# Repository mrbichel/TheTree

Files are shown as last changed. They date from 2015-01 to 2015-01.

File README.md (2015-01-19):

Helpful notes

tube 
ø indre 105
ø ydre 110

Power input 12 V

Calculations:
- LED current is approximately equal to: 0.5 / R3
- R3 power: the power dissipated by the resistor is approximately: 0.25 / R3. choose a resistor value at least 2x the power calculated so the resistor does not get burning hot.

so for 700mA LED current:
R3 = 0.5 / 0.7 = 0.71 ohms. closest standard resistor is 0.75 ohms.
R3 power = 0.25 / 0.71 = 0.35 watts. we'll need at least a 1/2 watt rated resistor.

Brand new and high quality.
High brightness, light and color consistency.
Color: Red, Green, Blue.
Viewing Angle: 140 degree.
Wavelength: R:620-630nm G:515-525nm B:460-470nm.
Voltage(Vf): R:2.0-2.5V G:3.2-3.6V B:3.2-3.86.
Luminous intensity: R:30-35lm G:40-45lm B:15-20lm.
Current: each 350mA

Wo for 350mA LED current:
R3 = 0.5 / 0.35 = 1.42857142857 ohms. closest standard resistor is 1.5 ohms.
R3 power = 0.25 / 1.42857142857 = 0.175 watts.
We use two 3.3 Ohm resistors

3 in parralell calculation
We have 350 mA LEDS
x3 = 1050

R3 = 0.5/1.05 = 0.47619047619
R3 power = 0.25 / 0.47619047619 = 0.525 W 

Standard resistors are 1/4W so 2 of them si okish 
In parralllel the closest we get to 0.47619047619 ohm with two standard resistors is with two 1 ohm resistors

    pcb2gcode --back /home/parallels/Desktop/psf/TheTree/3leds/series/inseries_copperBottom.gbl --drill   /home/parallels/Desktop/psf/TheTree/3leds/series/inseries_drill.txt --outline /home/parallels/Desktop/psf/TheTree/3leds/series/inseries_contour.gm1 --zwork -0.2 --zsafe 25.0 --mill-feed 6 --mill-speed 30000 --metric --offset 2.0 --basename johandrill --zdrill -2.0 --zchange 10.0 --drill-feed 6 --drill-speed 20000 --cutter-diameter 3.0 --zcut -2.0 -cut-speed 20000
---

    pcb2gcode --back /home/parallels/Desktop/psf/TheTree/3leds/series/inseries_copperBottom.gbl --drill /home/parallels/Desktop/psf/TheTree/3leds/series/inseries_drill.txt --outline /home/parallels/Desktop/psf/TheTree/3leds/series/inseries_contour.gm1 --zwork -0.2 --zsafe 25.0 --mill-feed 6 --mill-speed 30000 --metric --offset 50 --basename johandrill --zdrill -2.0 --zchange 10.0 --drill-feed 6 --drill-speed 20000 --cutter-diameter 3.0 --zcut -2.0 --cut-speed 20000 --milldrill --fill-outline --outline-width 2

    --fill-outline --outline-width 2 for using fritzing outline file

http://chilipeppr.com/tinyg

http://simplegcoder.com/js_editor/

http://jscut.org/jscut.html#

http://simplegcoder.com/js_editor_framework/

http://fablabamersfoort.nl/drill2gcode/

    pcb2gcode --back /home/parallels/Desktop/psf/TheTree/3leds/series/inseries_copperBottom.gbl --drill /home/parallels/Desktop/psf/TheTree/3leds/series/inseries_drill.txt --outline /home/parallels/Desktop/psf/TheTree/3leds/series/inseries_contour.gm1 --zwork -0.008 --zsafe 1 --mill-feed 6 --mill-speed 30000 --offset 1 --basename __newdrill --zdrill -0.07 --zchange 0.4 --drill-feed 6 --drill-speed 20000 --cutter-diameter 0.015 --zcut -0.07 --cut-speed 20000 --fill-outline --outline-width 0.01

Remember to connect MAX485 pin to ground with jumper

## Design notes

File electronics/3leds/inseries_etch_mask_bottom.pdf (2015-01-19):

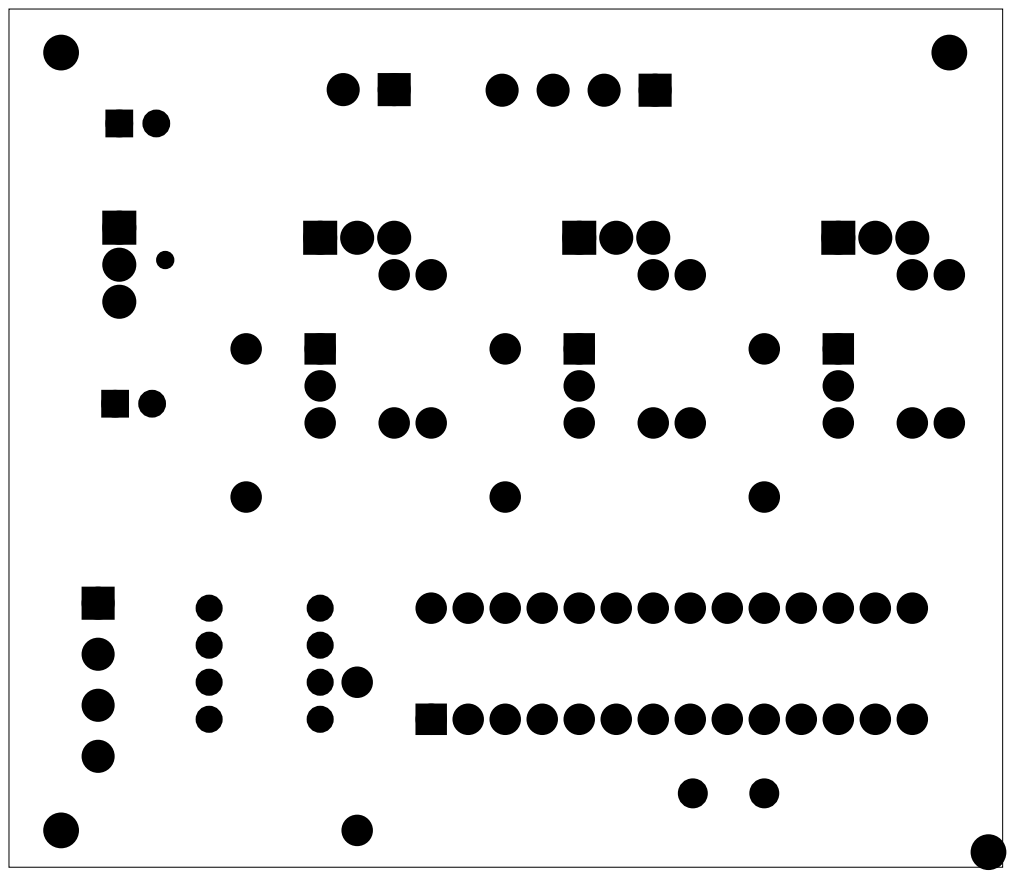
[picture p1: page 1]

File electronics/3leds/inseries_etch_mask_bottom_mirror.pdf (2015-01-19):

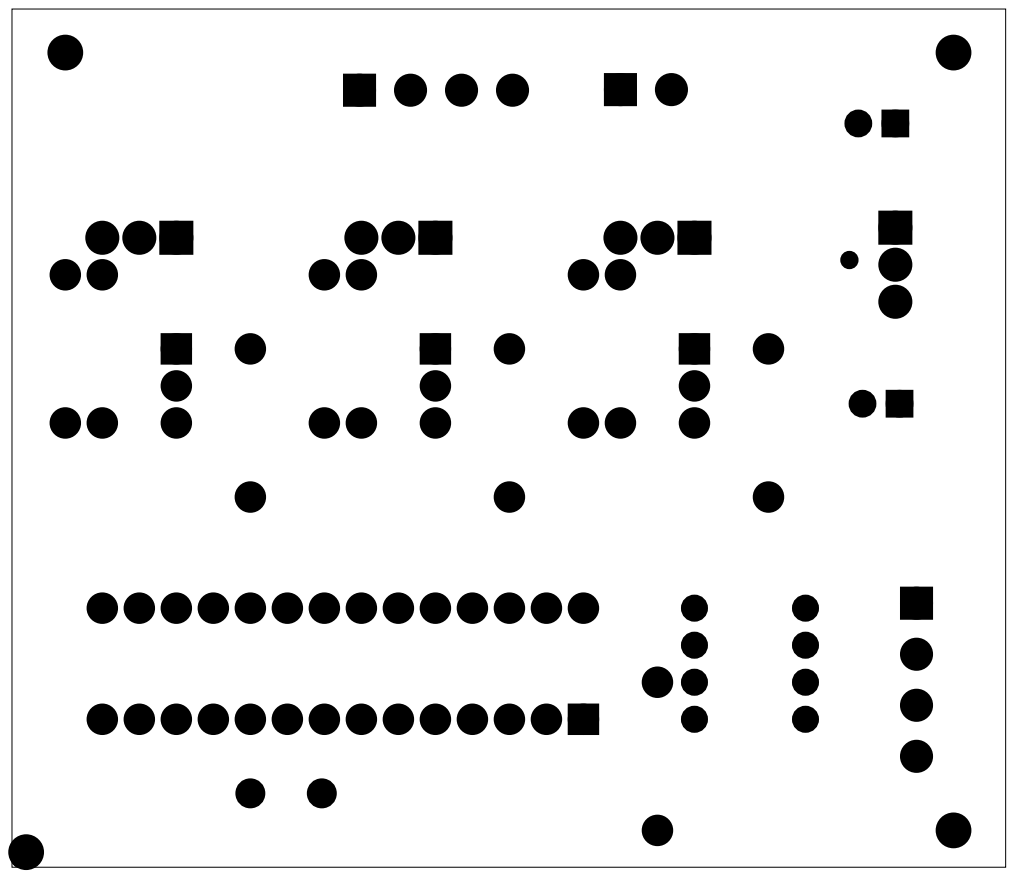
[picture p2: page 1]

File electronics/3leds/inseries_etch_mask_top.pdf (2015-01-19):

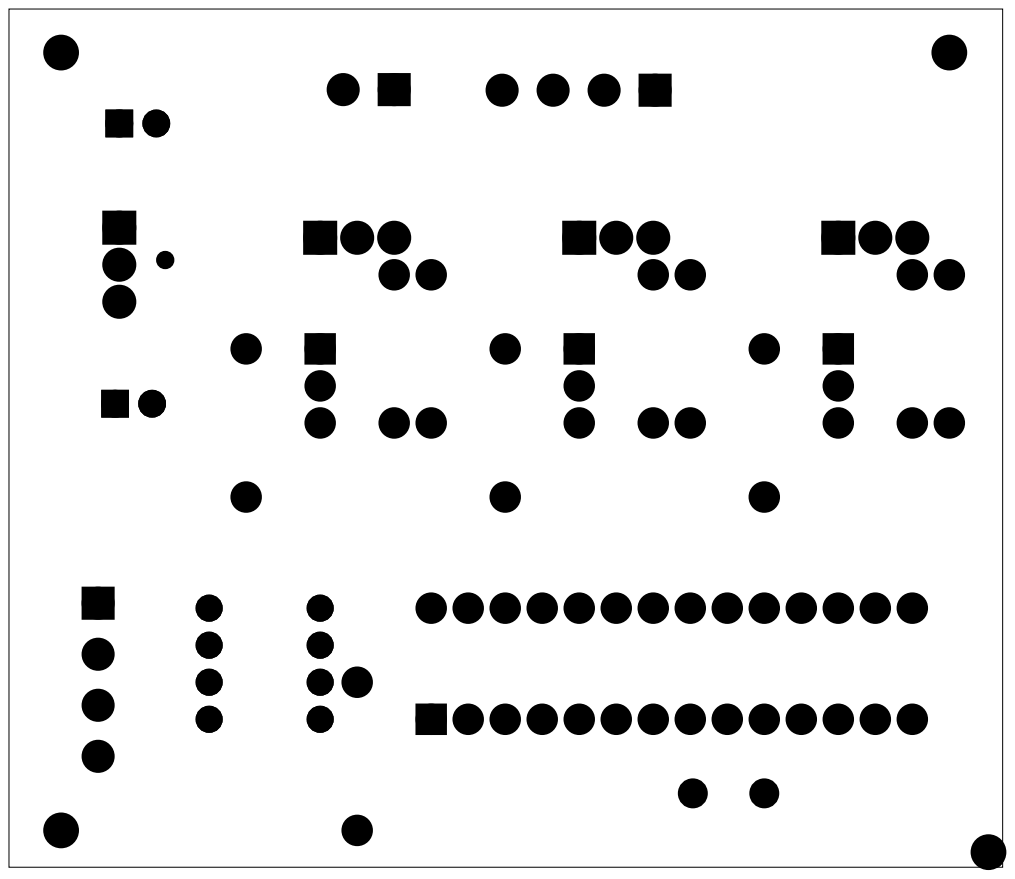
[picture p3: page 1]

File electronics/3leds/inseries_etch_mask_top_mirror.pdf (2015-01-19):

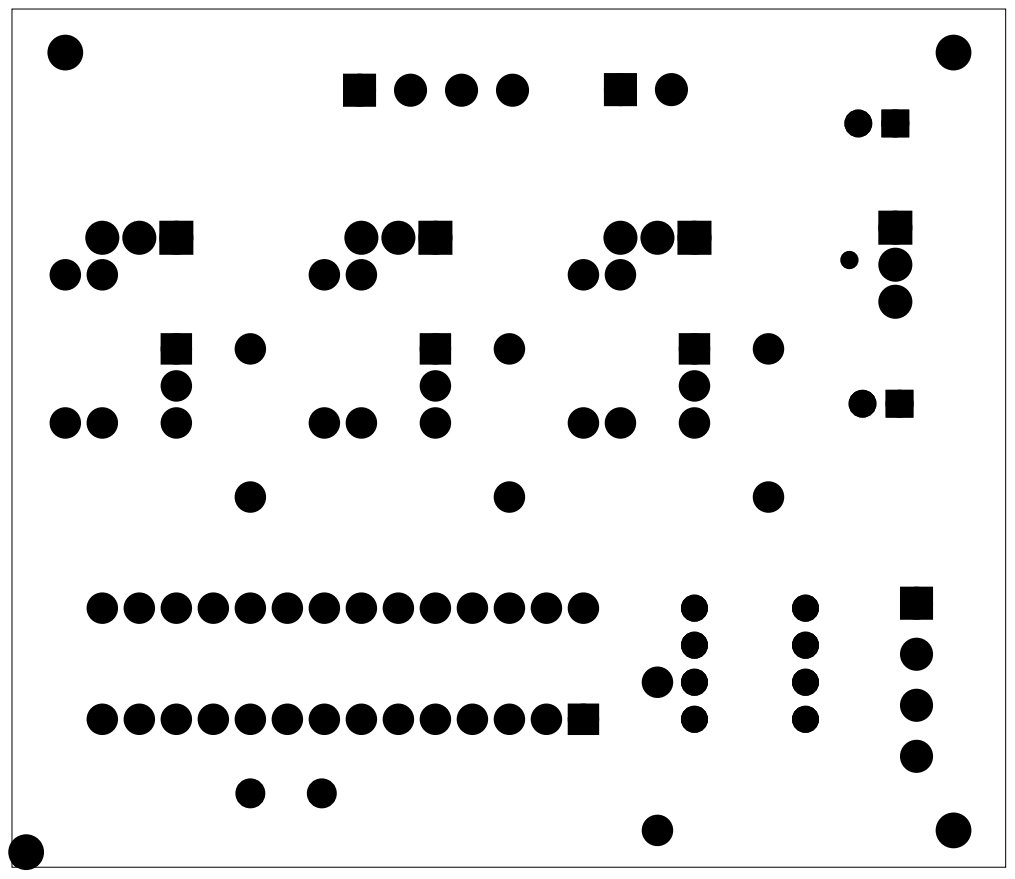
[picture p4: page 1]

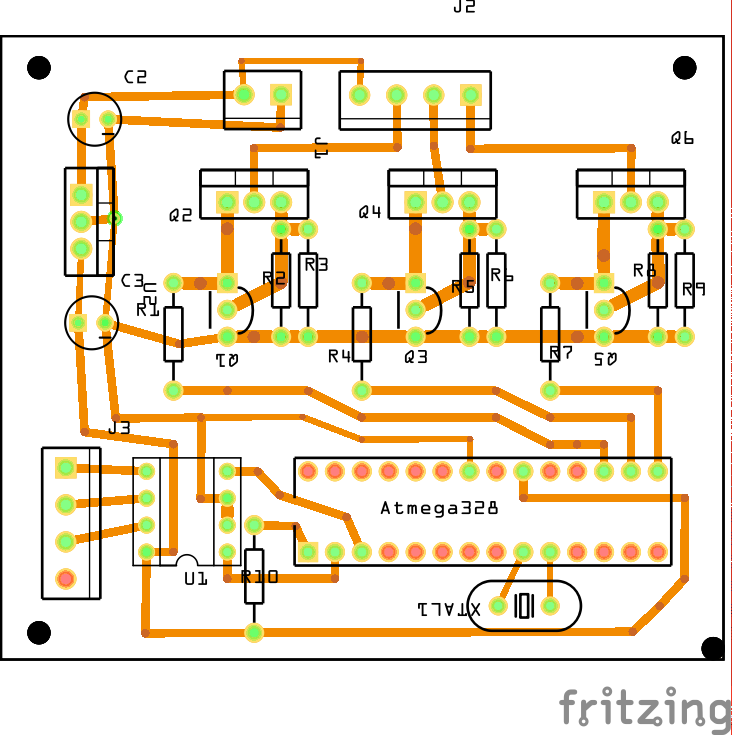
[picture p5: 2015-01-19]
electronics/3leds/inseries_pcb_b.png

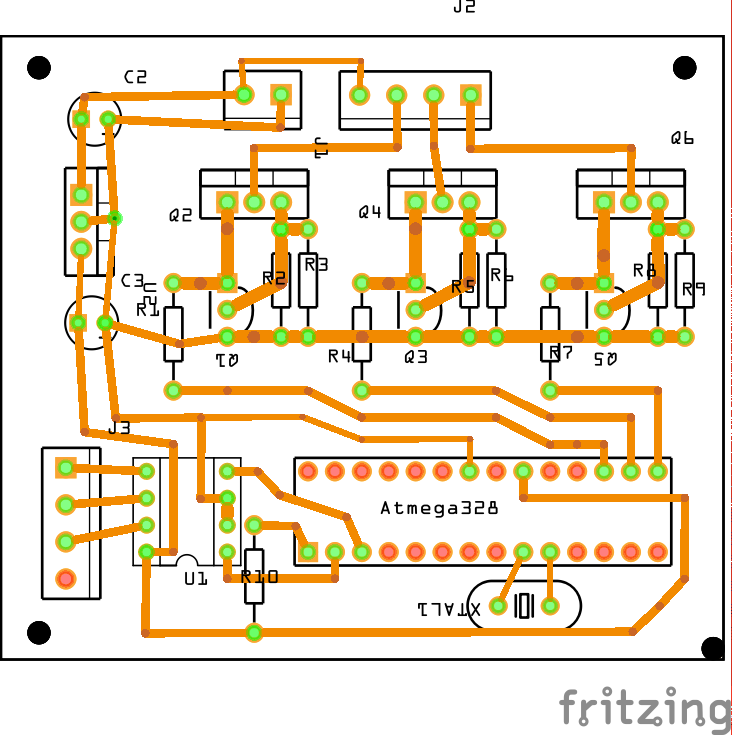
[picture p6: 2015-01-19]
electronics/3leds/inseries_pcb.png

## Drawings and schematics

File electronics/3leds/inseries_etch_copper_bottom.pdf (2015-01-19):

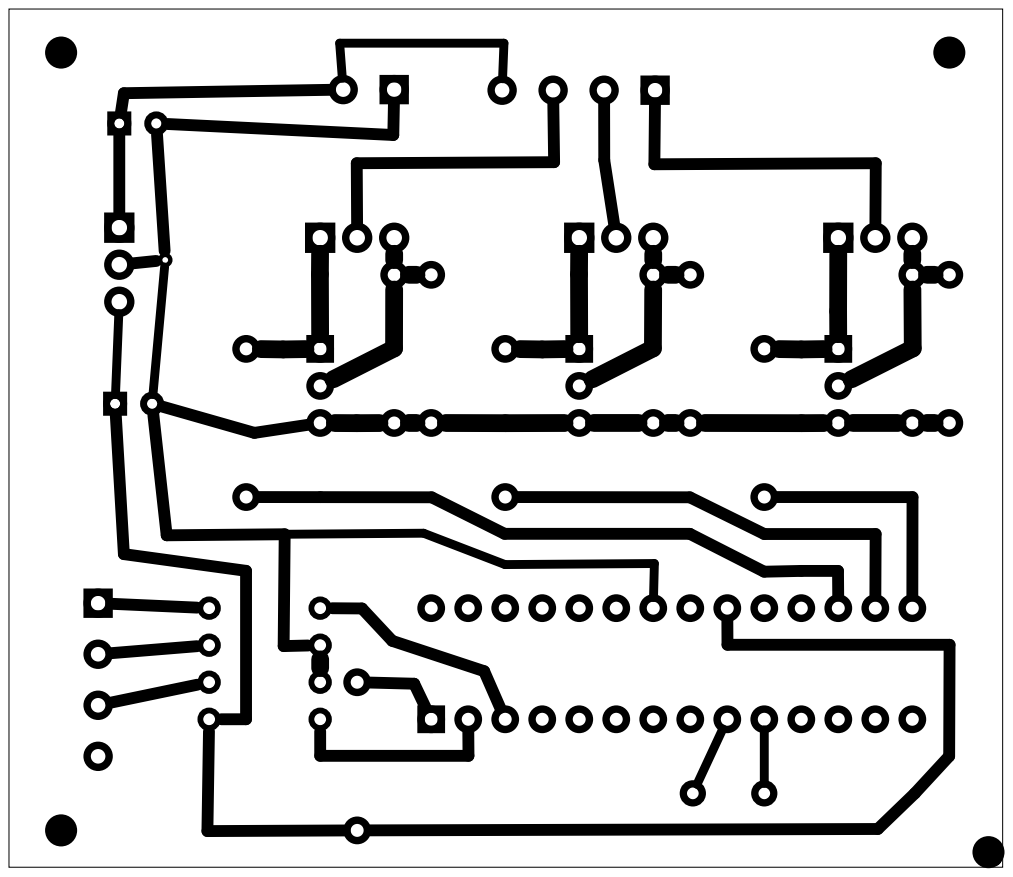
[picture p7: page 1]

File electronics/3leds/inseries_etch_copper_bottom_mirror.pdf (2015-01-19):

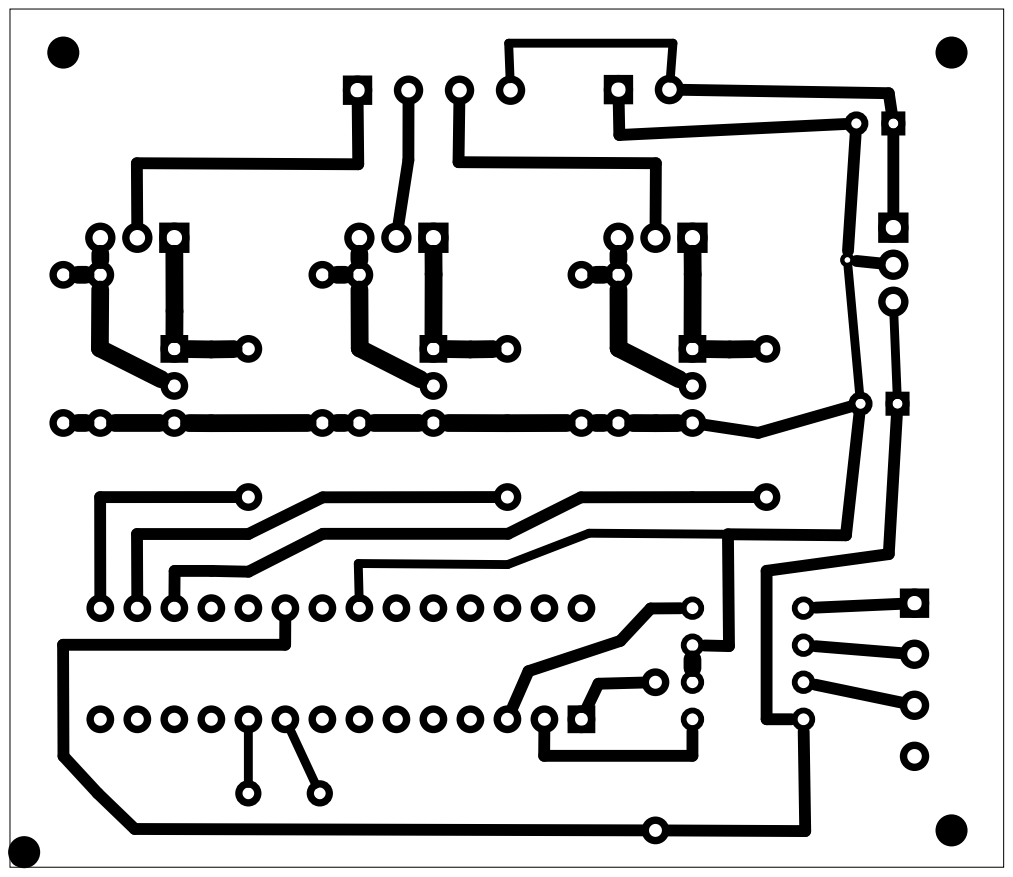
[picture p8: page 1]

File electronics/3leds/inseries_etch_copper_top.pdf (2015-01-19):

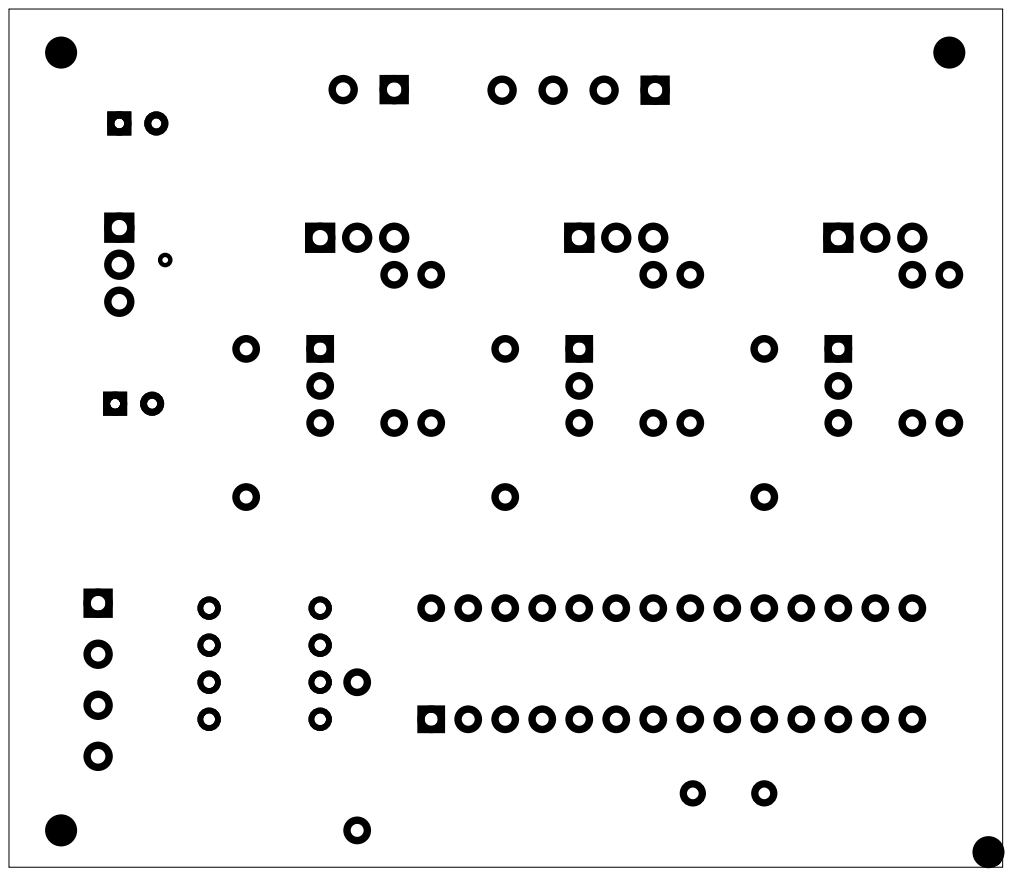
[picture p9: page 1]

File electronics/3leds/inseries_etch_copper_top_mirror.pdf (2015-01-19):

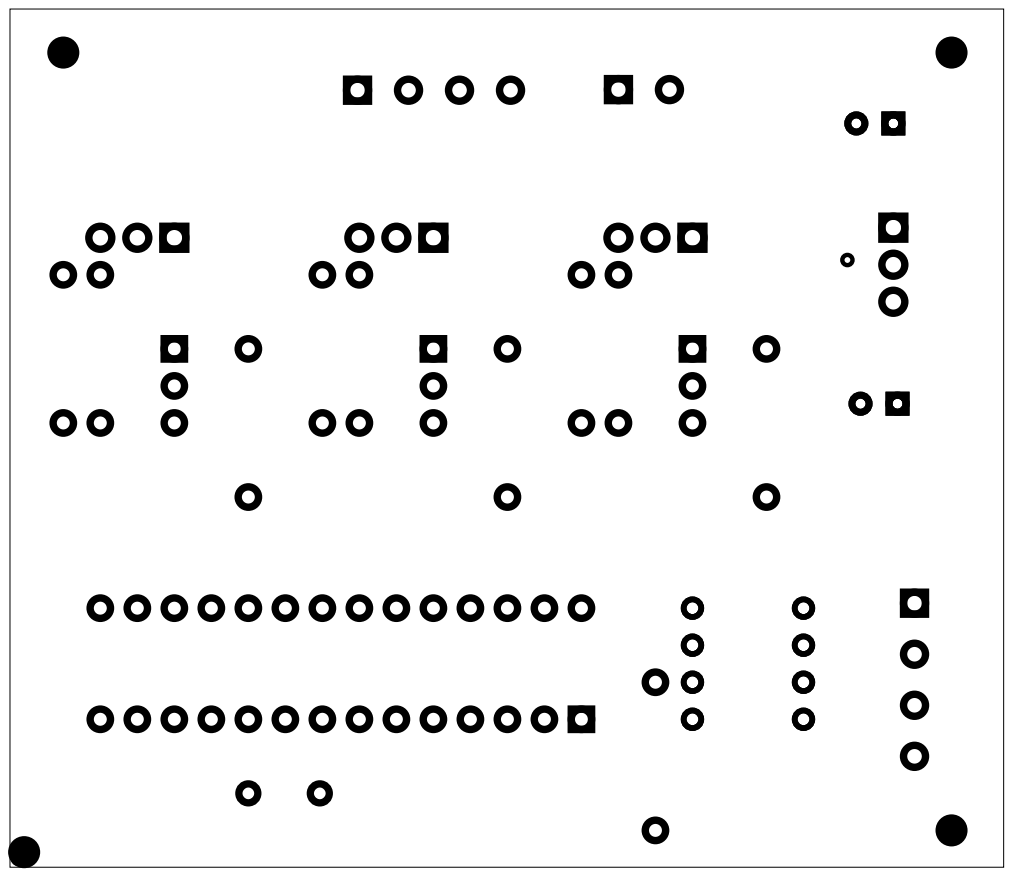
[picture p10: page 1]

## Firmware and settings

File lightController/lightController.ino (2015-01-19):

#include <HSBColor.h>

// - - - - -
// DmxSerial - A hardware supported interface to DMX.
// DmxSerialRecv.ino: Sample DMX application for retrieving 3 DMX values:
// address 1 (red) -> PWM Port 9
// address 2 (green) -> PWM Port 6
// address 3 (blue) -> PWM Port 5
// 
// Copyright (c) 2011 by Matthias Hertel, http://www.mathertel.de
// This work is licensed under a BSD style license. See http://www.mathertel.de/License.aspx
// 
// Documentation and samples are available at http://www.mathertel.de/Arduino
// 25.07.2011 creation of the DmxSerial library.
// 10.09.2011 fully control the serial hardware register
//            without using the Arduino Serial (HardwareSerial) class to avoid ISR implementation conflicts.
// 01.12.2011 include file and extension changed to work with the Arduino 1.0 environment
// 28.12.2011 changed to channels 1..3 (RGB) for compatibility with the DmxSerialSend sample.
// 10.05.2012 added some lines to loop to show how to fall back to a default color when no data was received since some time.
// - - - - -

#include <DMXSerial.h>

// Constants for demo program
const int RedPin   =   9;  // PWM output pin for Red Light.
const int GreenPin =  10;  // PWM output pin for Green Light.
const int BluePin  =  11;  // PWM output pin for Blue Light.

int rbg_array[3];

int dmxAddress = 19; //1,2,3  4,5,6  7 8 9     10 11 12,        13, 14, 15     16 17 18,  19 20 21   22 23 24

void setup () {
  DMXSerial.init(DMXReceiver);
 
  // set some default values
  DMXSerial.write(1, 0);
  DMXSerial.write(2, 0);
  DMXSerial.write(3, 0);
  
  // enable pwm outputs
  pinMode(RedPin,   OUTPUT); // sets the digital pin as output
  pinMode(GreenPin, OUTPUT);
  pinMode(BluePin,  OUTPUT);
  
}

void loop() {
  // Calculate how long no data backet was received
  unsigned long lastPacket = DMXSerial.noDataSince();
  
  if (lastPacket < 5000) {
    // read recent DMX values and set pwm levels 
    analogWrite(RedPin,   DMXSerial.read(dmxAddress));
    analogWrite(GreenPin, DMXSerial.read(dmxAddress+1));
    analogWrite(BluePin,  DMXSerial.read(dmxAddress+2));

  } else {
    
    float b1 = float(millis())/810.0f;   
    float h1 = float(millis())/5060.0f;
    float s1 = float(millis())/1460.0f;  
  
    float hue = perlinNoise1D(h1);
    float sat = perlinNoise1D(s1);
    float val = perlinNoise1D(b1);
    
    H2R_HSBtoRGBfloat(hue, sat, val, rbg_array);
        
    analogWrite(RedPin,   rbg_array[0]);
    analogWrite(GreenPin, rbg_array[1]);
    analogWrite(BluePin,  rbg_array[2]);
    
  } // if
}

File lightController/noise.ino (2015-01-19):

#define kPerlinOctaves      3
static const float kaPerlinOctaveAmplitude[kPerlinOctaves] =
{
  0.75f, 0.4f, 0.1f,
};

float perlinNoise1( long x )
{
  x = ( x<<13 ) ^ x;
  return ( 1.0f - ( (x * (x * x * 15731 + 789221L) + 1376312589L) & 0x7fffffff) * (1.0f / 1073741824.0f) );
}

float perlinSmoothedNoise1( long x )
{
  return perlinNoise1(x)*0.5f
       + perlinNoise1(x-1)*0.25f
       + perlinNoise1(x+1)*0.25f;
}

float perlinLerpedNoise1( float x )
{
  long  xInteger  = long(x);
  float xFraction = x - xInteger;

  float v1 = perlinSmoothedNoise1( xInteger );
  float v2 = perlinSmoothedNoise1( xInteger + 1 );

  return lerpFloat( v1, v2, xFraction );
}

float perlinNoise1D( float x )
{
  float total = 0.0f;

  for( int octave = 0; octave < kPerlinOctaves; octave++ )
  {
    int   frequency = 1 << octave;
    float amplitude = kaPerlinOctaveAmplitude[octave];

    total += perlinLerpedNoise1( x * frequency ) * amplitude;
  }

  // map from [-1,1] to [0,1] and constrain
  return constrain( (total + 1.0f) * 0.5f, 0.0f, 1.0f );
}
